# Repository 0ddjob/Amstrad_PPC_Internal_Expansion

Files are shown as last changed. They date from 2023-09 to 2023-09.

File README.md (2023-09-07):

# Amstrad_PPC_XT_CF_Lite
Internal CF interface for the Amstrad PPC512/640

Replaces the internal modem board with a combination ISA interface & XT-IDE/Compact Flash interface.<br> 

Heavily based on Sergey Kiselev's design<br>
[Github page](https://github.com/skiselev)<br>
[WWW page](http://www.malinov.com/Home/sergeys-projects/xt-cf-lite)<br>

Which is apparently a remake of James Pearce's card:<br>
[WWW page](http://www.lo-tech.co.uk/wiki/XT-CF-lite)<br>

I am using some of Sergey's Kicad symbols/footprints:<br>
[Sergey's Kicad symbols](https://github.com/skiselev/my_kicad_library)<br>

Changes requires for internal mounting in the Amstrad PPC:<br>
[1] The following signals are generated directly from the internal gate arrays and should be buffered with a non-inverting buffer (i.e. 72HC244): A00 to A07, !MEMW, !MEMR, !IOW, !IOR, RESET<br>
_(there are others but irrelevant for our purposes)_<br>
[2] The data signals (D0 to D7) are at CMOS levels and should be pulled up to TTL levels with 10KΩ resistors<br>
[3] The internal modem board we are replacing is roughly 200x120mm<br>
[4] Technically the PPC should be powered by the "expansion unit" and not the other way around ... don't tell anyone<br>

Currently untested ...<br><br>
Amstrad_PPC_Internal_Modem
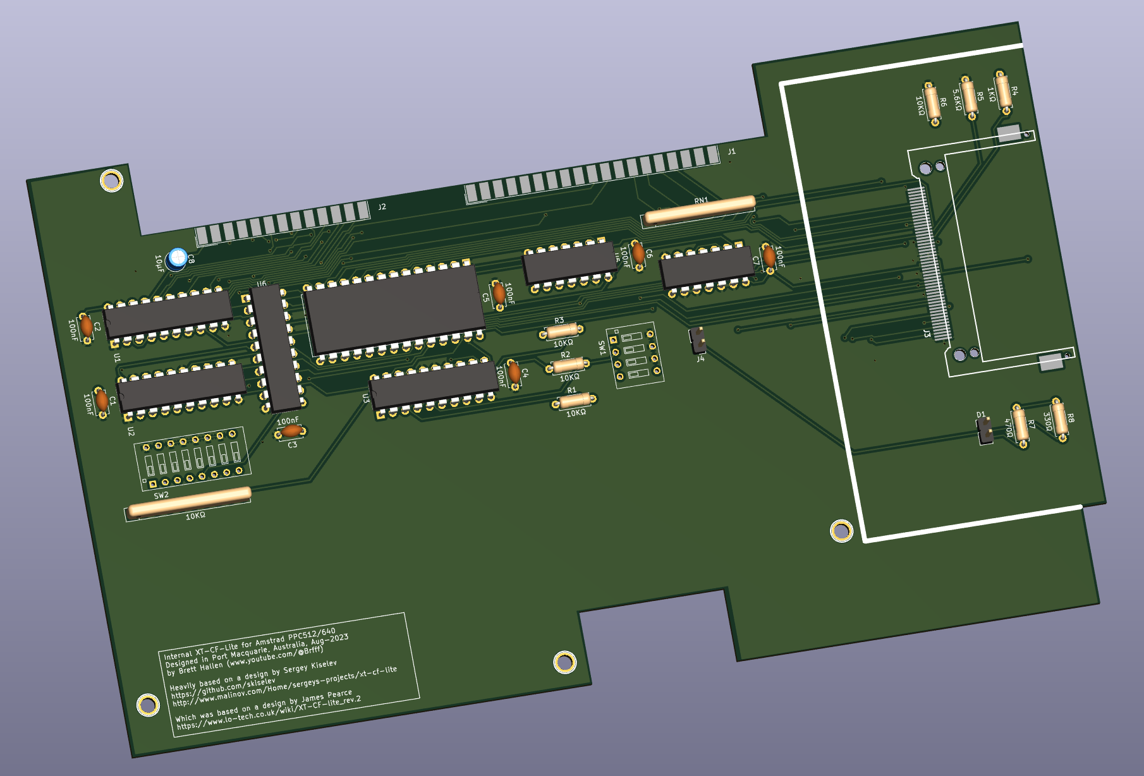
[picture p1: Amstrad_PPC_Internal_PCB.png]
Amstrad_PPC_Internal_CF_Lite


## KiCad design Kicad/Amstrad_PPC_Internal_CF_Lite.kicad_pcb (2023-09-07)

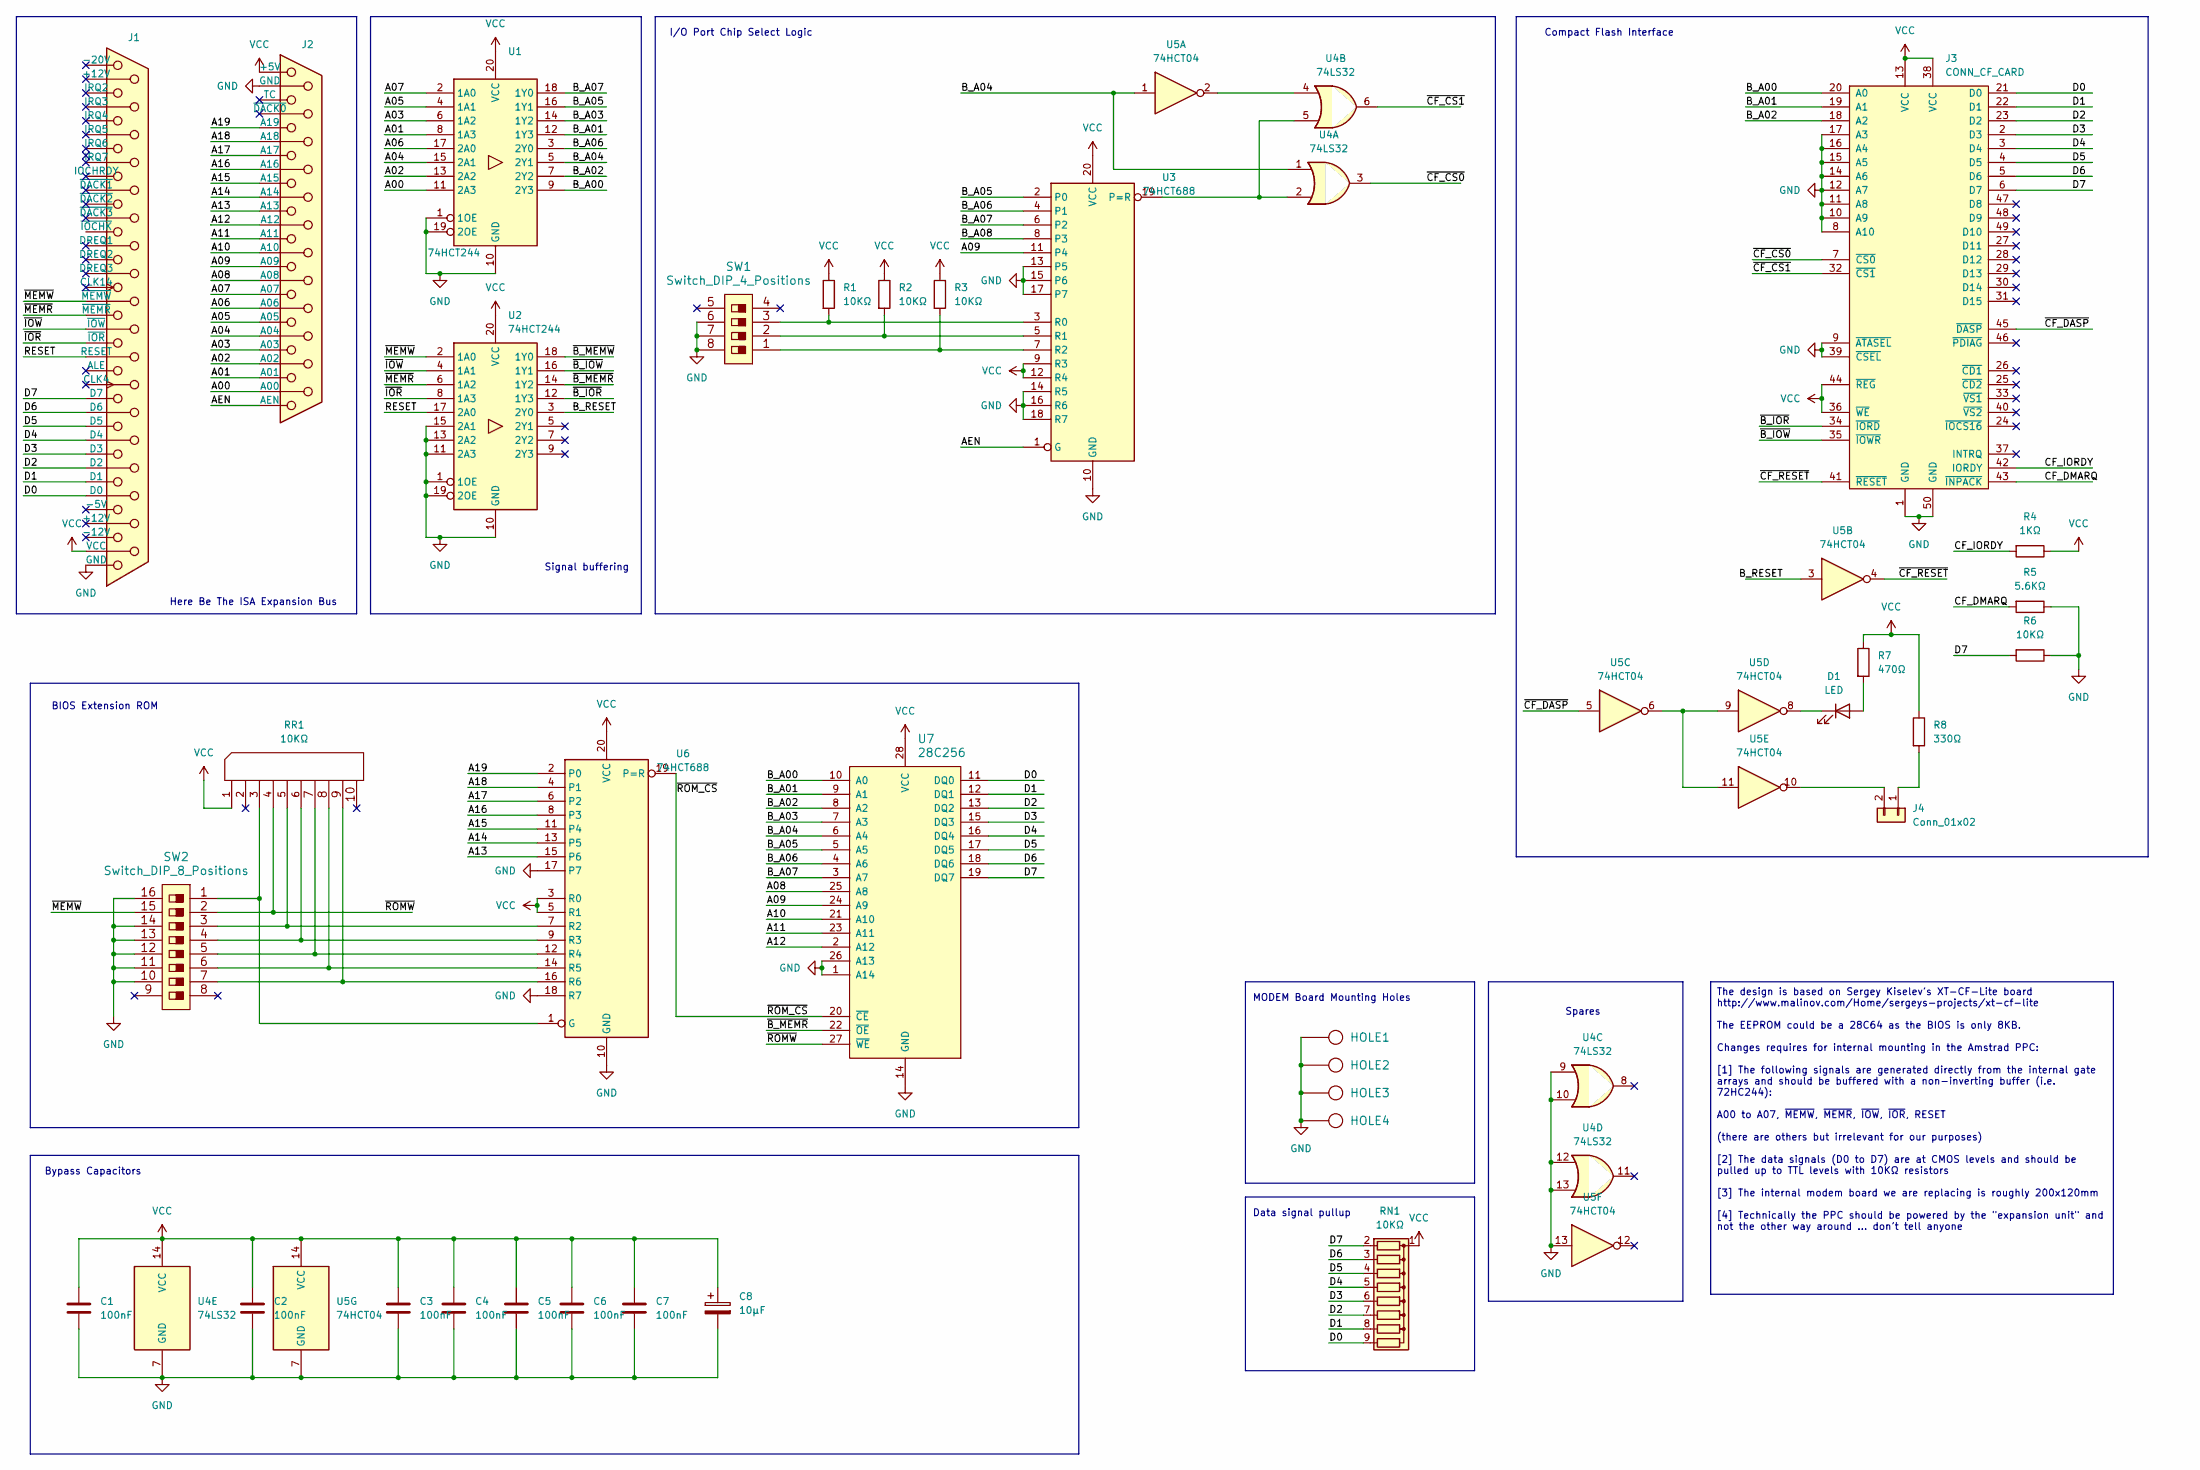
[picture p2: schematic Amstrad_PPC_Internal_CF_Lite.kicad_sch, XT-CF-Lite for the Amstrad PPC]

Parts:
C1, C2, C3, C4, C5, C6, C7: 100nF; C_Disc_D4.7mm_W2.5mm_P5.00mm
C8: 10µF; C_Radial_D4.0mm_H5.0mm_P1.50mm
D1: LED; PinHeader_1x02_P2.54mm_Vertical
HOLE1, HOLE2, HOLE3, HOLE4: HOLE; Hole_3mm
J1: Amstrad_PPC_ISA_Connector_B; DSUB-37_Female_EdgeMount_P2.77mm
J2: Amstrad_PPC_ISA_Connector_A; DSUB-25_Female_EdgeMount_P2.77mm
J3: CONN_CF_CARD; Conn_CF_N7E50-Q516XX-40
J4: Conn_01x02; PinHeader_1x02_P2.54mm_Vertical
R1, R2, R3, R6: 10KΩ; R_Axial_DIN0207_L6.3mm_D2.5mm_P7.62mm_Horizontal
R4: 1KΩ; R_Axial_DIN0207_L6.3mm_D2.5mm_P7.62mm_Horizontal
R5: 5.6KΩ; R_Axial_DIN0207_L6.3mm_D2.5mm_P7.62mm_Horizontal
R7: 470Ω; R_Axial_DIN0207_L6.3mm_D2.5mm_P7.62mm_Horizontal
R8: 330Ω; R_Axial_DIN0207_L6.3mm_D2.5mm_P7.62mm_Horizontal
RN1: 10KΩ; R_Array_SIP9
RR1: 10KΩ; R_Array_SIP10
SW1: Switch_DIP_4_Positions
SW2: Switch_DIP_8_Positions
U1, U2: 74HCT244; DIP-20_W7.62mm
U3, U6: 74HCT688; DIP-20_W7.62mm
U4: 74LS32; DIP-14_W7.62mm
U5: 74HCT04; DIP-14_W7.62mm
U7: 28C256; DIP-28_W15.24mm

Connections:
/A00: J2.25 (A00), U1.11 (2A3)
/A01: J2.12 (A01), U1.8 (1A3)
/A02: J2.24 (A02), U1.13 (2A2)
/A03: J2.11 (A03), U1.6 (1A2)
/A04: J2.23 (A04), U1.15 (2A1)
/A05: J2.10 (A05), U1.4 (1A1)
/A06: J2.22 (A06), U1.17 (2A0)
/A07: J2.9 (A07), U1.2 (1A0)
/A08: J2.21 (A08), U7.25 (A8)
/A09: J2.8 (A09), U3.11 (P4), U7.24 (A9)
/A10: J2.20 (A10), U7.21 (A10)
/A11: J2.7 (A11), U7.23 (A11)
/A12: J2.19 (A12), U7.2 (A12)
/A13: J2.6 (A13), U6.15 (P6)
/A14: J2.18 (A14), U6.13 (P5)
/A15: J2.5 (A15), U6.11 (P4)
/A16: J2.17 (A16), U6.8 (P3)
/A17: J2.4 (A17), U6.6 (P2)
/A18: J2.16 (A18), U6.4 (P1)
/A19: J2.3 (A19), U6.2 (P0)
/AEN: J2.13 (AEN), U3.1 (G)
/B_A00: J3.20 (A0), U1.9 (2Y3), U7.10 (A0)
/B_A01: J3.19 (A1), U1.12 (1Y3), U7.9 (A1)
/B_A02: J3.18 (A2), U1.7 (2Y2), U7.8 (A2)
/B_A03: U1.14 (1Y2), U7.7 (A3)
/B_A04: U1.5 (2Y1), U4.1, U5.1, U7.6 (A4)
/B_A05: U1.16 (1Y1), U3.2 (P0), U7.5 (A5)
/B_A06: U1.3 (2Y0), U3.4 (P1), U7.4 (A6)
/B_A07: U1.18 (1Y0), U3.6 (P2), U7.3 (A7)
/B_A08: U3.8 (P3)
/B_RESET: U2.3 (2Y0)
/CF_DMARQ: J3.43 (~INPACK), R5.2
/CF_IORDY: J3.42 (IORDY), R4.2
/D0: J1.35 (D0), J3.21 (D0), RN1.9 (R8), U7.11 (DQ0)
/D1: J1.16 (D1), J3.22 (D1), RN1.8 (R7), U7.12 (DQ1)
/D2: J1.34 (D2), J3.23 (D2), RN1.7 (R6), U7.13 (DQ2)
/D3: J1.15 (D3), J3.2 (D3), RN1.6 (R5), U7.15 (DQ3)
/D4: J1.33 (D4), J3.3 (D4), RN1.5 (R4), U7.16 (DQ4)
/D5: J1.14 (D5), J3.4 (D5), RN1.4 (R3), U7.17 (DQ5)
/D6: J1.32 (D6), J3.5 (D6), RN1.3 (R2), U7.18 (DQ6)
/D7: J1.13 (D7), J3.6 (D7), R6.2, RN1.2 (R1), U7.19 (DQ7)
/RESET: J1.30 (RESET), U2.17 (2A0)
/~B_IOR: J3.34 (~IORD), U2.12 (1Y3)
/~B_IOW: J3.35 (~IOWR), U2.16 (1Y1)
/~B_MEMR: U2.14 (1Y2), U7.22 (~OE)
/~B_MEMW: U2.18 (1Y0)
/~CF_CS0: J3.7 (~CS0), U4.3
/~CF_CS1: J3.32 (~CS1), U4.6
/~CF_DASP: J3.45 (~DASP), U5.5
/~CF_RESET: J3.41 (~RESET), U5.4
/~IOR: J1.11 (~IOR), U2.8 (1A3)
/~IOW: J1.29 (~IOW), U2.4 (1A1)
/~MEMR: J1.10 (~MEMR), U2.6 (1A2)
/~MEMW: J1.28 (~MEMW), SW2.15, U2.2 (1A0)
/~ROMW: RR1.4, SW2.2, U7.27 (~WE)
/~ROM_CS: U6.19 (P=R), U7.20 (~CE)
GND: C1.2, C2.2, C3.2, C4.2, C5.2, C6.2, C7.2, C8.2, HOLE1.1, HOLE2.1, HOLE3.1, HOLE4.1, J1.19 (GND), J2.14 (GND), J3.1 (GND), J3.8 (A10), J3.9 (~ATASEL), J3.10 (A9), J3.11 (A8), J3.12 (A7), J3.14 (A6), J3.15 (A5), J3.16 (A4), J3.17 (A3), J3.39 (~CSEL), J3.50 (GND), R5.1, R6.1, SW1.6, SW1.7, SW1.8, SW2.10, SW2.11, SW2.12, SW2.13, SW2.14, SW2.16, U1.1 (1OE), U1.10 (GND), U1.19 (2OE), U2.1 (1OE), U2.10 (GND), U2.11 (2A3), U2.13 (2A2), U2.15 (2A1), U2.19 (2OE), U3.10 (GND), U3.13 (P5), U3.14 (R5), U3.15 (P6), U3.16 (R6), U3.17 (P7), U3.18 (R7), U4.7 (GND), U4.9, U4.10, U4.12, U4.13, U5.7 (GND), U5.13, U6.10 (GND), U6.17 (P7), U6.18 (R7), U7.1 (A14), U7.14 (GND), U7.26 (A13)
unnamed: D1.2 (A), R7.2
unnamed: D1.1 (K), U5.8
unnamed: J4.1, R8.2
unnamed: J4.2, U5.10
unnamed: U3.19 (P=R), U4.2, U4.5
unnamed: R1.2, SW1.3, U3.3 (R0)
unnamed: R2.2, SW1.2, U3.5 (R1)
unnamed: R3.2, SW1.1, U3.7 (R2)
unnamed: U4.4, U5.2
unnamed: U5.6, U5.9, U5.11
unnamed: RR1.3, SW2.1, U6.1 (G)
unnamed: RR1.5, SW2.3, U6.7 (R2)
unnamed: RR1.6, SW2.4, U6.9 (R3)
unnamed: RR1.7, SW2.5, U6.12 (R4)
unnamed: RR1.8, SW2.6, U6.14 (R5)
unnamed: RR1.9, SW2.7, U6.16 (R6)
VCC: C1.1, C2.1, C3.1, C4.1, C5.1, C6.1, C7.1, C8.1, J1.37 (VCC), J2.1 (+5V), J3.13 (VCC), J3.36 (~WE), J3.38 (VCC), J3.44 (~REG), R1.1, R2.1, R3.1, R4.1, R7.1, R8.1, RN1.1 (common), RR1.1 (COM), U1.20 (VCC), U2.20 (VCC), U3.9 (R3), U3.12 (R4), U3.20 (VCC), U4.14 (VCC), U5.14 (VCC), U6.3 (R0), U6.5 (R1), U6.20 (VCC), U7.28 (VCC)

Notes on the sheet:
The design is based on Sergey Kiselev's XT-CF-Lite board http://www.malinov.com/Home/sergeys-projects/xt-cf-lite The EEPROM could be a 28C64 as the BIOS is only 8KB. Changes requires for internal mounting in the Amstrad PPC: [1] The following signals are generated directly from the internal gate ar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
Signal buffering
Spares
Compact Flash Interface
I/O Port Chip Select Logic
BIOS Extension ROM
Data signal pullup
MODEM Board Mounting Holes
Here Be The ISA Expansion Bus
Bypass Capacitors

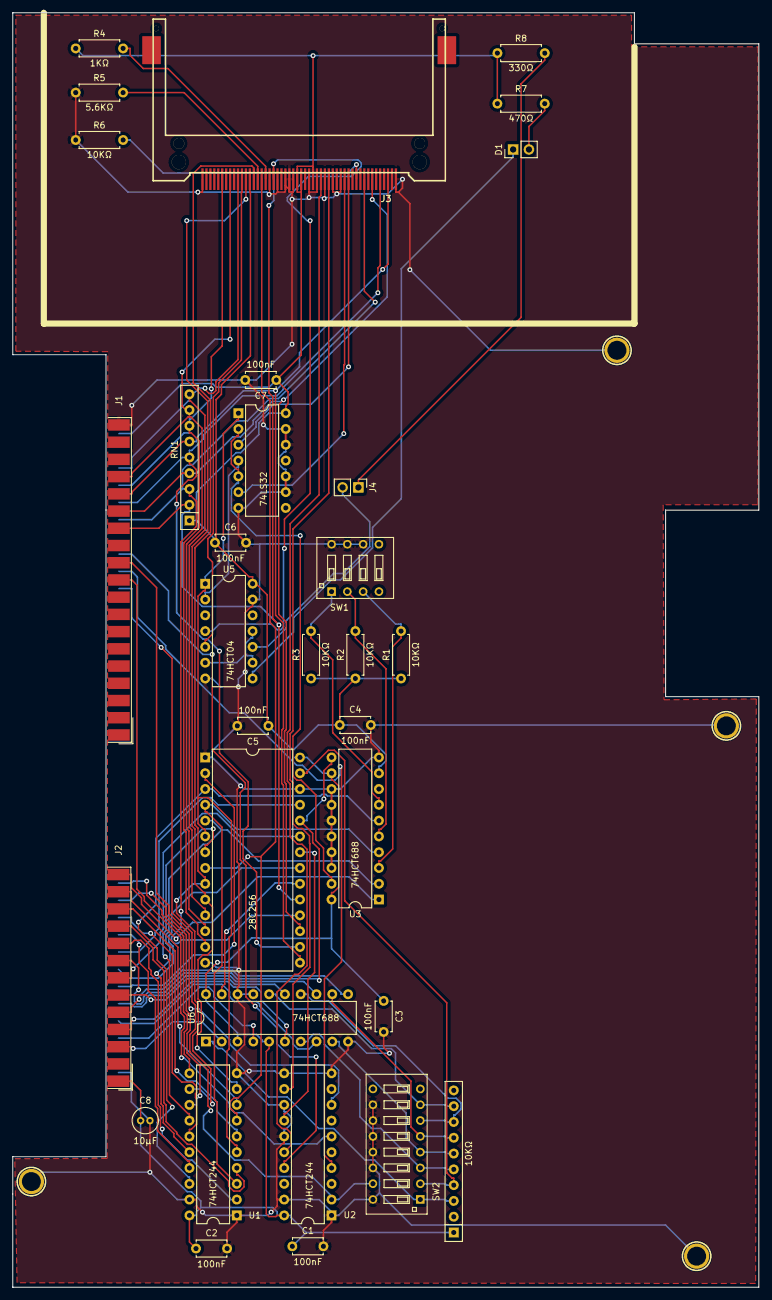
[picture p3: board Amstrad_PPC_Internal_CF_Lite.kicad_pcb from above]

Board: 2 copper layers, 120.0 x 205.0 mm, 36 parts (0 on the bottom side), 71 nets.

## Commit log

2023-08-24 Initial/untested set of Kicad 7 files
    It ain't pretty ... and it ain't tested ... this is my first project using Kicad so it'll be a bit rough still ...
2023-08-24 Added note about Sergey's Kicad symbol library
2023-09-07 Refinements to PCB
    [Amstrad_PPC_Internal_CF_Lite.kicad_pcb, Amstrad_PPC_Internal_CF_Lite.kicad_sch]
2023-09-07 Added PCB image
